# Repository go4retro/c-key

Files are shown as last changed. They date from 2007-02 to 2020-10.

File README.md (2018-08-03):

#Commodore PS/2 Keyboard Adapter

##License
Copyright (C) 2004 Jim Brain and RETRO Innovations

These files are free designs; you can redistribute them and/or modify
them under the terms of the GNU General Public License, version 2 as 
published by the Free Software Foundation.

These files are distributed in the hope that they will be useful,
but WITHOUT ANY WARRANTY; without even the implied warranty of
MERCHANTABILITY or FITNESS FOR A PARTICULAR PURPOSE.  See the
GNU General Public License for more details.

You should have received a copy of the GNU General Public License along
with these files; if not, write to the Free Software Foundation, Inc.,
51 Franklin Street, Fifth Floor, Boston, MA 02110-1301 USA.

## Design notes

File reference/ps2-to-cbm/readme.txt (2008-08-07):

Commodore to PS/2 keyboard & mouse adapter

0.0 Introduction

The Commodore to PS/2 keyboard & mouse adapter will let you use a regular PS/2 keyboard and PS/2 mouse on your Commodre 64 or VIC20. The keyboard is emulated using symbolic (not positional) mapping and the mouse emulates a 1531 mouse in proportional mode. 

0.1 Quick start guide

For those who don't like reading long documents, here is what you need:
- get all the parts listed in the "parts" section below
- assemble the circuit as per the schematic
- program the MCU
- connect C64, mouse, and keyboard

1.0 Parts

The following parts are required:

- Microcontroller PIC18F4520-I/P (40 pin DIP)
- Crosspoint switch MT8812AP1 (or MT8812AP)
- 10 MHz crystal
- 20-pin 0.100" header
- DE-9F connector 
- 6-pin min-DIN connector (qty 2)
- 220 ohm resistors (qty 15 or qty 2 8-way network)
- 180 ohm resistors (qty 16 or qty 2 8-way network)
- 150 ohm resistors (qty 3) (optional)
- 4.7 Kohm resistor (qty 4)
- 10 Kohm resistor
- LED (qty 3) (optional)
- 0.1 uF capacitor (qty 3)
- RCA connectors (qty 3) (optional)

2.0 Operation

2.1 Keyboard emulation
Almost all the PS/2 keys correspond to their C64 equivalents, so F1 is F1, CTRL is CTRL, etc.
The following five keys don't exist on the PS/2 keyboard so here are the substiutes:

C64 pound key      ==> PS/2 backslash  (\)
C64 left arrow key ==> PS/2 left quote (`)
C64 restore key	   ==> PS/2 pause/break
C64 run/stop key   ==> PS/2 esc
C64 commodore key  ==> PS/2 Windows key

Also, since three keys (@ ^ and +) require using the shift key, they themselves can't be combined with the shift key. This will only pose a problem if you're doing keyboard graphics (in which case a real C64 keyboard is probably more useful anyway since a PS/2 keyboard doesn't have the symbols on the front of the keys).

All the remaining keys on the PS/2 keyboard that don't map to a C64 equivalent will have no effect when pressed.

Caps Lock also has no effect since the typical function of a caps locks key is to only type uppercase letters, whereas the C64 "shift lock" key causes EVERY key to be shifted.

2.2 Mouse emulation

The mouse emulation simulates a 1531 mouse in proportional mode and is compatible with the 1531 driver for Geos. There is no emulation of a 1530 joystick-type mouse or of the 1531 in joystick mode.

2.3 Special functions

A few extra features are available:
If you have a Super Snapshot cartridge, connect the button to pin 2 of the CPU and pressing F12 will push the snapshot button.

If you have an A/B switch for your joystick, connect the control line to pin 23 of the CPU and pressing num lock will toggle between joystick 1 and joystick 2.

If you want to be able to reset your C64 from the keyboard, connect pin 24 of the CPU to the input of the 556 chip inside the C64 and pressing ctrl-alt-del will reset the C64.

3.0 Modifications

To compile the project, you will need the CCS compiler (www.ccsinfo.com) version 3.249. Version 4.xxx should work as well. From the "File" menu select "Open" and choose "main.c". Press F9 to compile.

Since the code only uses 22% of the ROM on the PIC18F4520, an equivalent CPU with less ROM can be used to save cost. 

To change the key mappings, edit TABLES.C and change the main translation table. Any PS/2 scancode can be mapped to any key, including the extra keys found on multimedia keyboards.

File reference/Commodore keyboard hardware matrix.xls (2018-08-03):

 | 13 br/wh | 19 red/wh | 18 or/wh | 17 yel/wh | 16 gr/wh | 15 bl/wh | 14 pur/wh | 20 gr/wh
12 brown | 1 | 3 | 5 | 7 | 9 | plus | brit# | inst/del
11 red | left arrow | W | R | Y | I | P | * | return
10 orange | ctrl | A | D | G | J | L | semicolon | rgh/lft
5 yellow | run stop | l-shift-lck | X | V | N | comma | slash | up/dwn
8 green | space | Z | C | B | M | period | r-shift | F1
7 blue | commodr | S | F | H | K | colon | equals | F3
6 purple | Q | E | T | U | O | at sign | up arrow | F5
9 gray | 2 | 4 | 6 | 8 | 0 | minus | clr/home | F7
4 5v
3 Restore | black/white
1 Ground

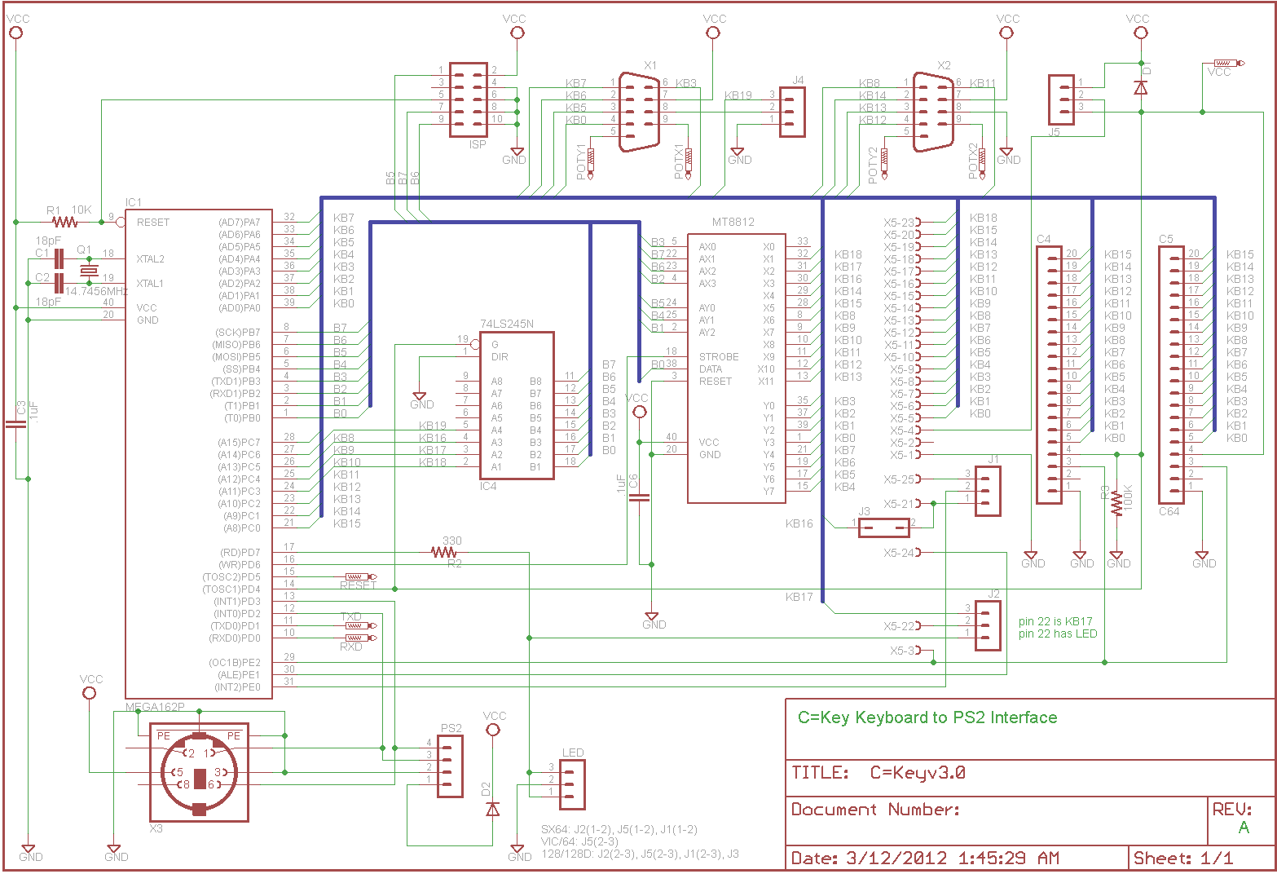
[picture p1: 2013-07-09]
pcb/C=Key 3.0a Schematic.png

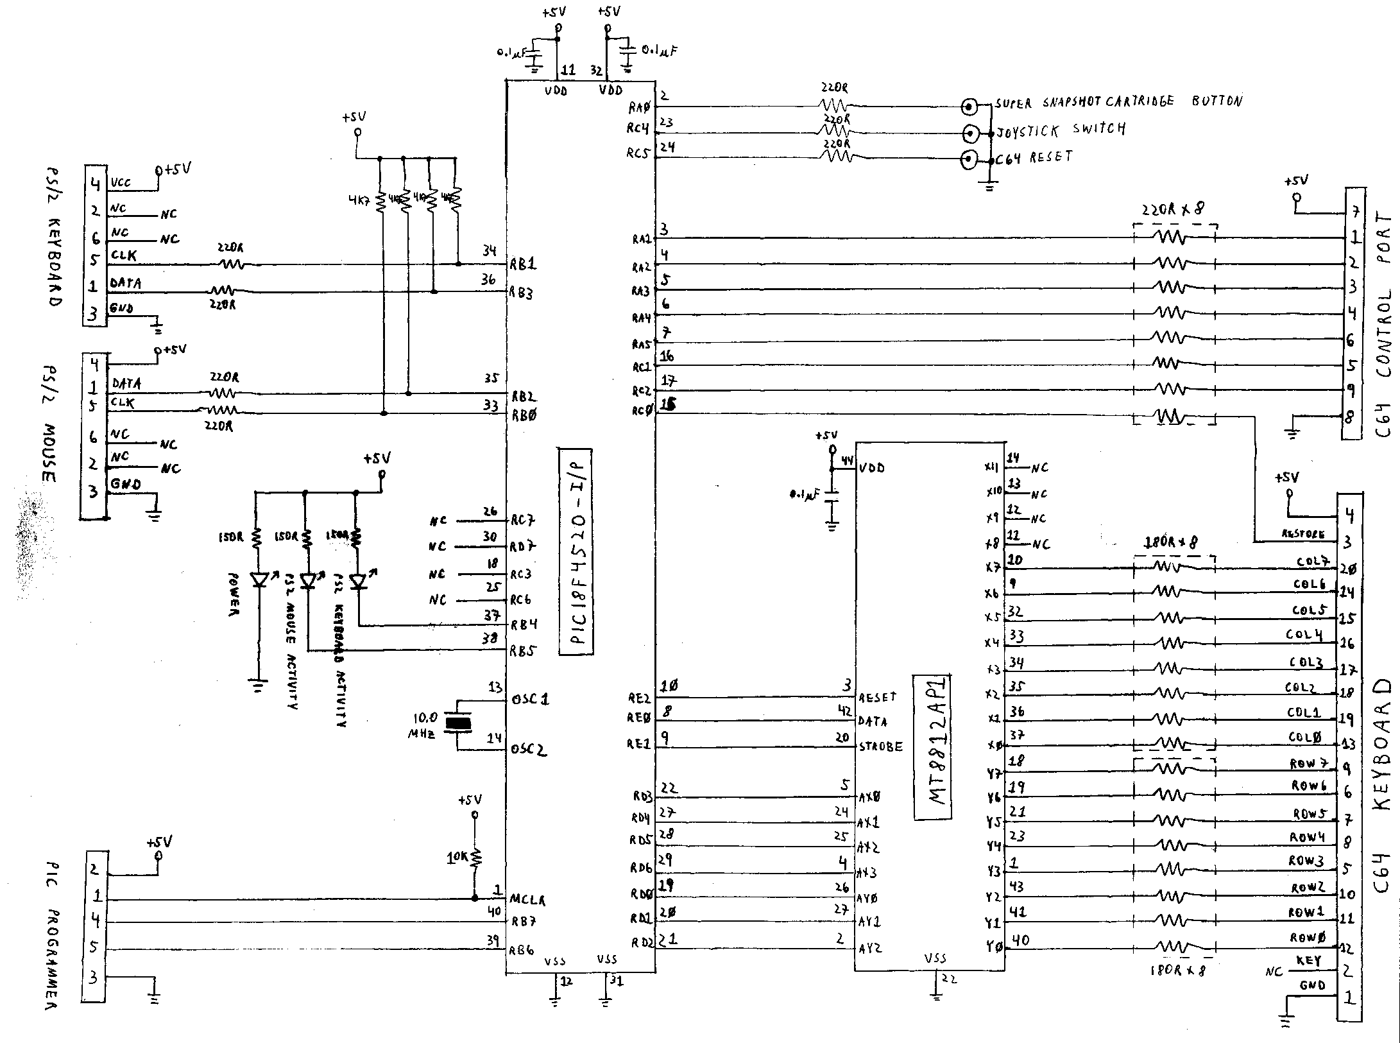
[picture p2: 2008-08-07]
reference/ps2-to-cbm/schematic.gif

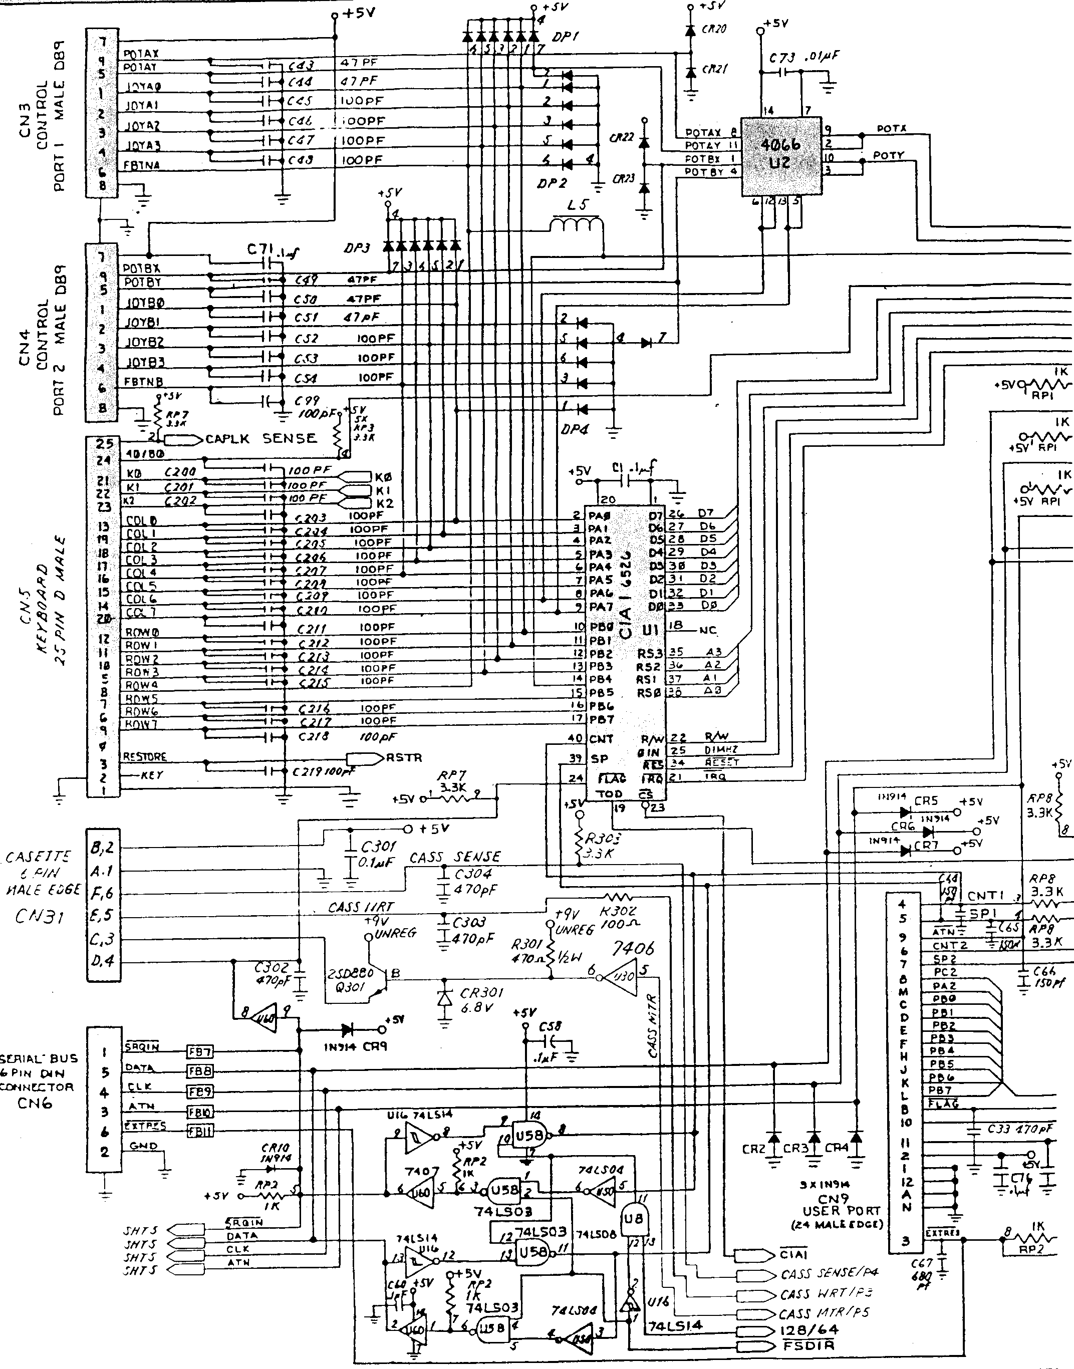
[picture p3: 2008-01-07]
reference/c128dcr-1-left.gif

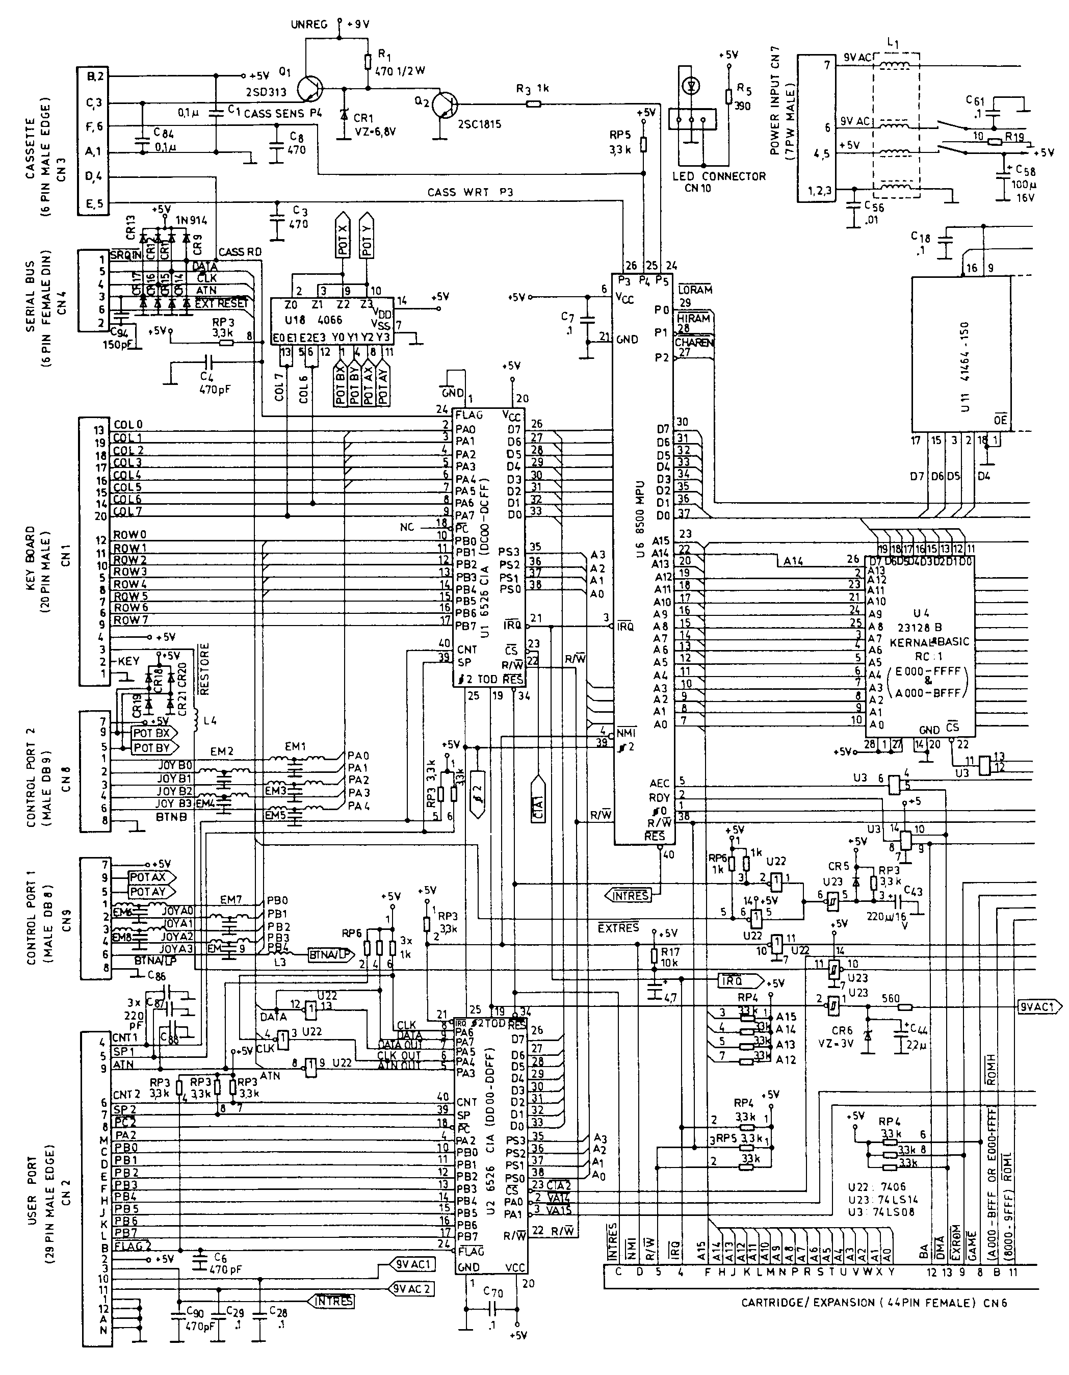
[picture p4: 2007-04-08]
reference/250469-rev.A-left.gif

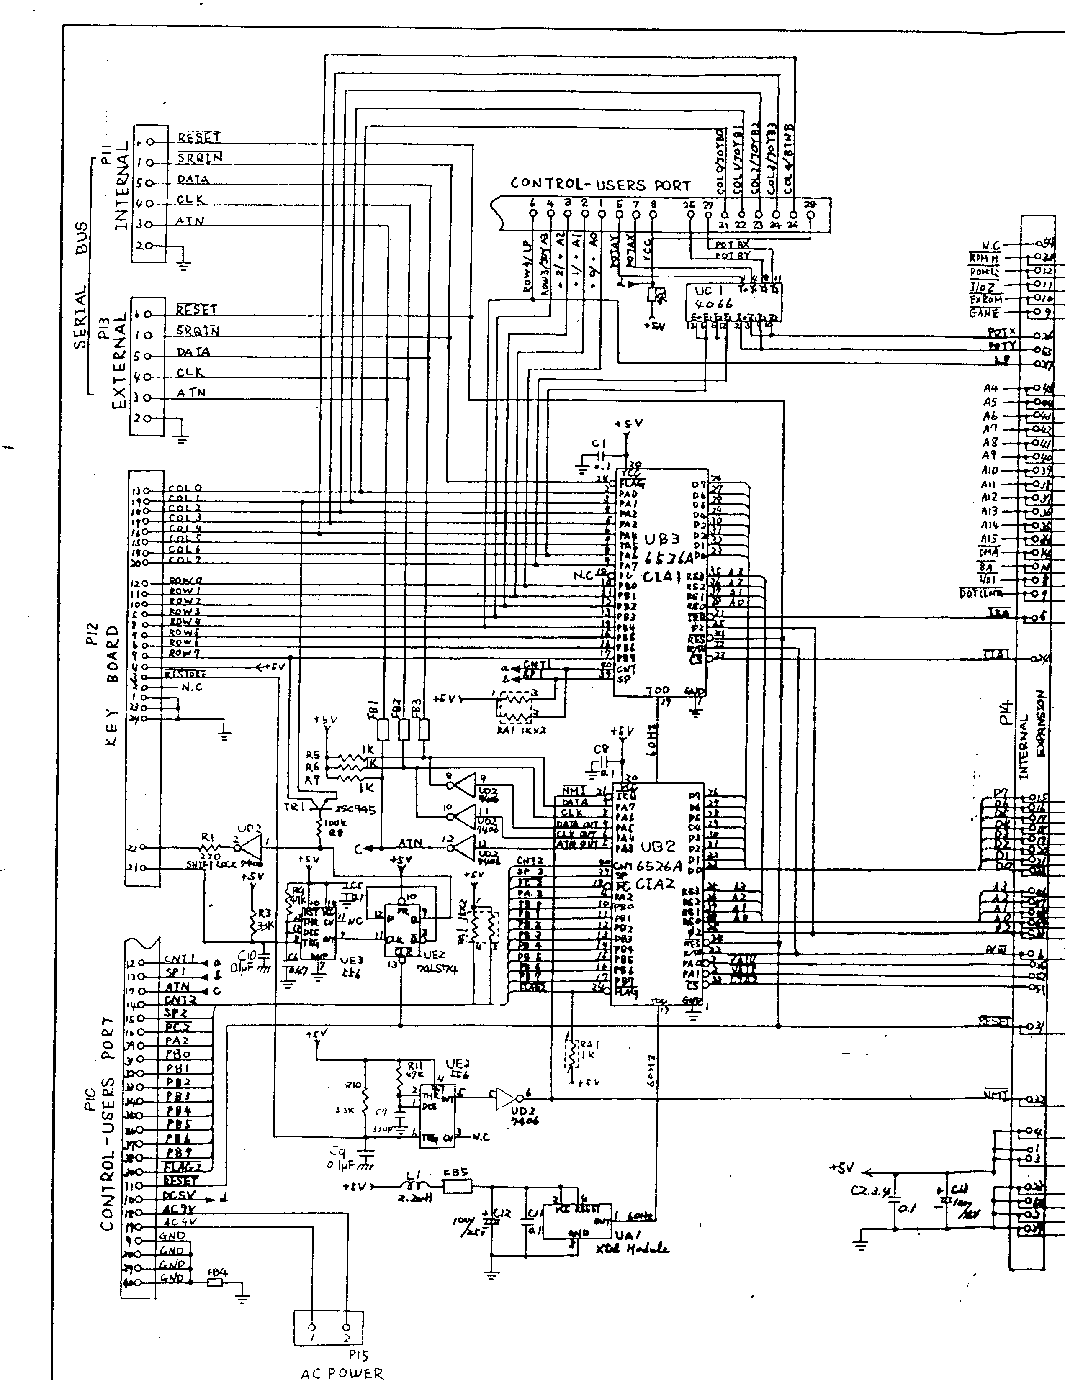
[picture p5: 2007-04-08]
reference/251107_l.gif

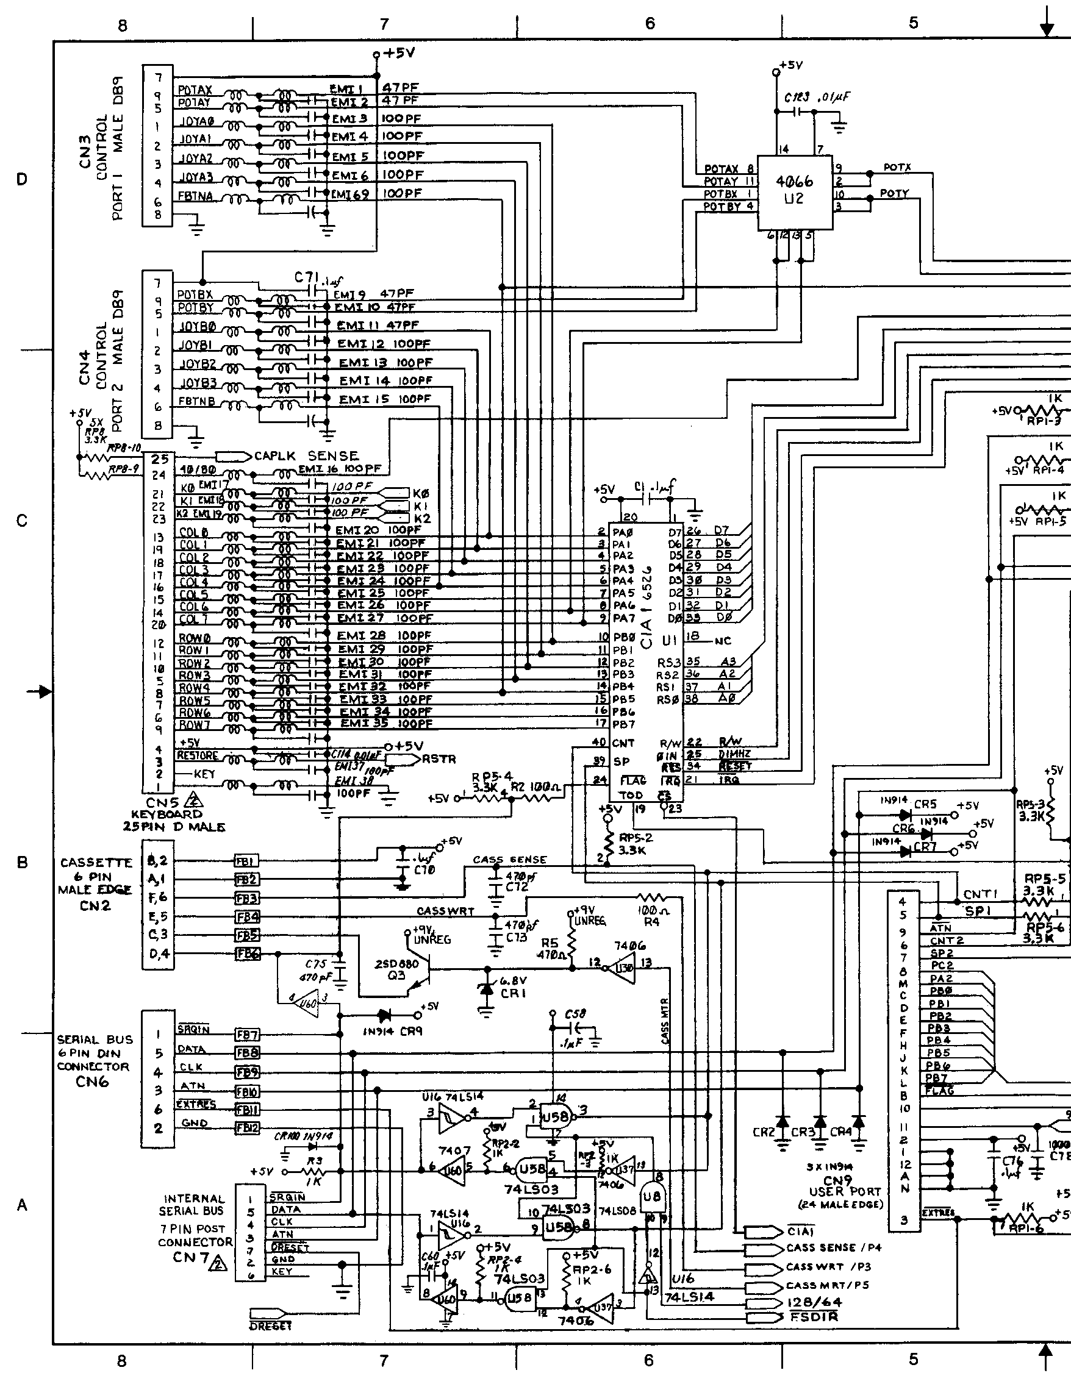
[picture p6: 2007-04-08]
reference/310378-3-left.gif

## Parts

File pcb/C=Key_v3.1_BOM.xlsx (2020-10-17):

Part | Value | Device | Quantity | Description | Source
C1,C2 | 18pF | C2.5/2 | 2 | CAPACITOR | https://www.digikey.com/en/products/detail/vishay-beyschlag-draloric-bc-components/K180J15C0GF5TL2/286458
C3,C6 | .1uF | C2.5/2 | 2 | CAPACITOR | https://www.digikey.com/en/products/detail/vishay-beyschlag-draloric-bc-components/K104K15X7RF5TL2/286538
C4 |  | MA20-1 | 1 | PIN HEADER | https://www.digikey.com/en/products/detail/sullins-connector-solutions/PPTC201LFBN-RC/810158
C5 | C64 | MA20-1 | 1 | PIN HEADER | https://www.digikey.com/en/products/detail/sullins-connector-solutions/PREC020SAAN-RC/2774834
D1,D2 |  | DIODE-DO41-10 | 2 | DIODE | https://www.digikey.com/en/products/detail/micro-commercial-co/1N4002-TP/773639
IC1 | MEGA162P | MEGA161P | 1 | MICROCONTROLLER | https://www.digikey.com/en/products/detail/microchip-technology/ATMEGA162-16PU/739761
IC2 | MT8812-P | MT8812-P | 1
IC4 | 74LS245N | 74LS245N | 1 | Octal BUS TRANSCEIVER, 3-state | https://www.digikey.com/en/products/detail/texas-instruments/SN74LS245N/277301
J1,J2,J5,LED |  | MA03-1 | 4 | PIN HEADER | https://www.digikey.com/en/products/detail/adam-tech/PH1-12-UA/9830395
J3 |  | JP1Q | 1 | JUMPER | https://www.digikey.com/en/products/detail/adam-tech/PH1-02-UA/9830266
PS2 |  | MA04-1 | 1 | PIN HEADER | https://www.digikey.com/en/products/detail/adam-tech/PH1-04-UA/9829296
Q1 | 14.7456MHz | CRYTALHC49U-V | 1 | CRYSTAL | https://www.digikey.com/en/products/detail/abracon-llc/ABL-14-7456MHZ-B2/675235
R1 | 10K | R-US_0204/5 | 1 | RESISTOR, American symbol | https://www.digikey.com/en/products/detail/stackpole-electronics-inc/CF18JT10K0/1741566
R2 | 330 | R-US_0204/5 | 1 | RESISTOR, American symbol | https://www.digikey.com/en/products/detail/stackpole-electronics-inc/CF18JT330R/1741683
R3 | 100K | R-US_0204/2V | 1 | RESISTOR, American symbol | https://www.digikey.com/en/products/detail/stackpole-electronics-inc/CF18JT100K/1741564
X1,X2 |  | M09HP | 2 | SUB-D | https://www.digikey.com/en/products/detail/assmann-wsw-components/A-DS-09-A-KG-T4S/1241806
X3 |  | MINI_DIN_6 | 1 | MINI_DIN_6 | https://www.digikey.com/en/products/detail/adam-tech/MDJ-006-FS/9832513
X5 |  | F25HPS | 1 | SUB-D | https://www.digikey.com/en/products/detail/amphenol-icc-fci/D25S33E4PA00LF/1538080

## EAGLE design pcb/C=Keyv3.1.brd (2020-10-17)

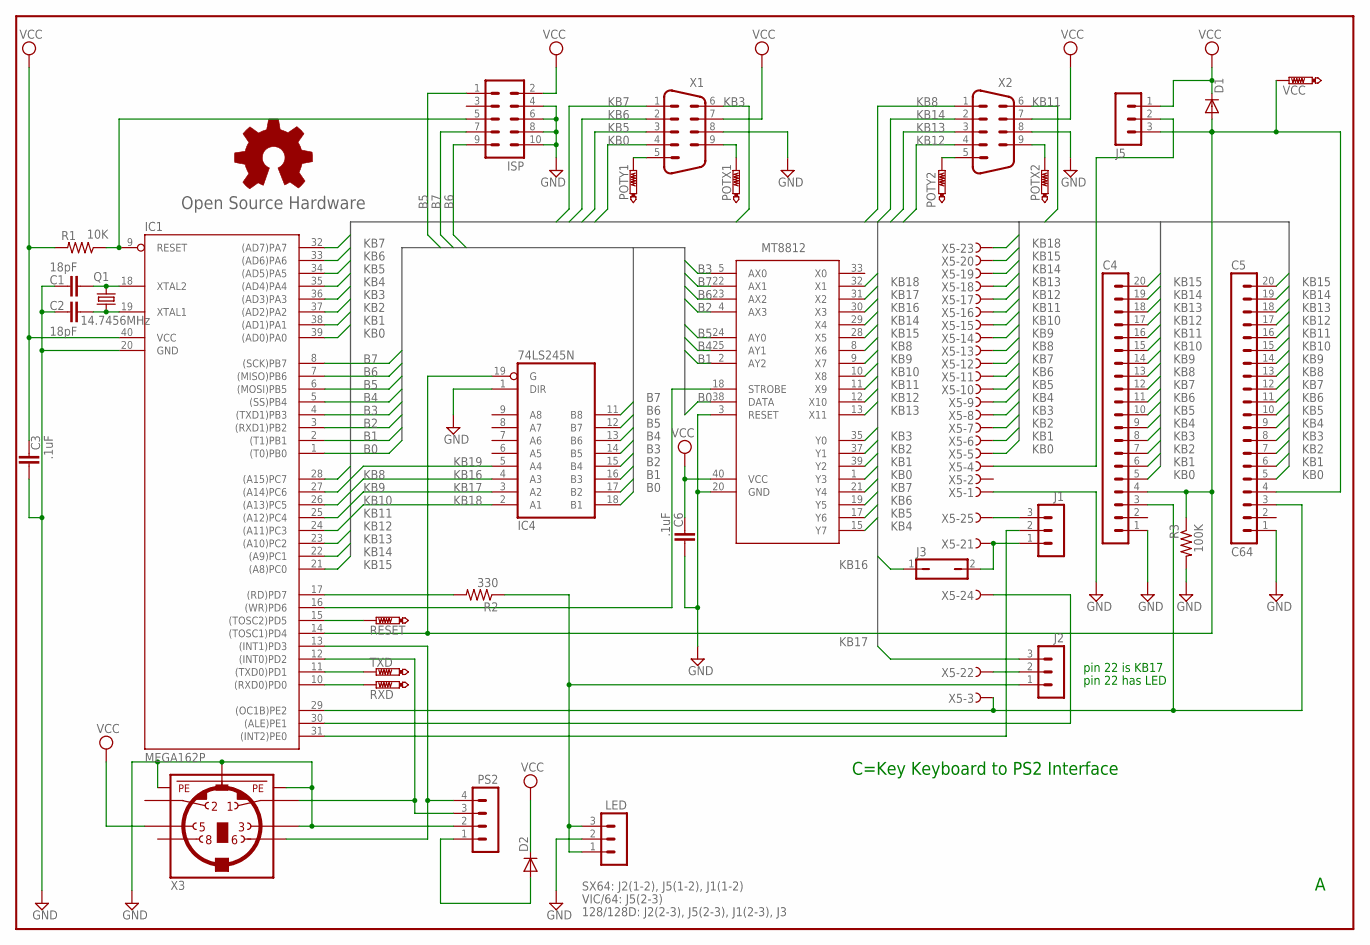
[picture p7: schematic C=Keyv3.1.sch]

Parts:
C1, C2: 18pF; C2.5-2
C3, C6: .1uF; C2.5-2
C4: MA20-1
C5: C64; MA20-1
D1, D2: DIODE-DO41-10; DO41-10
GOLD_ORB_SM1: Open Source Hardware; OSHW_5MM
IC1: MEGA162P; DIL40
IC2: MT8812-P; DIP40
IC4: 74LS245N; DIL20
ISP: MA05-2
J1, J2, J5: MA03-1
J3: JP1Q; JP1
LED: MA03-1
POTX1, POTX2: PTR1PAD1-13; P1-13
POTY1, POTY2: PTR1PAD1-13; P1-13
PS2: MA04-1
Q1: 14.7456MHz; HC49U-V
R1: 10K; 0204/5
R2: 330; 0204/5
R3: 100K; 0204V
RESET: PTR1PAD1-13; P1-13
RXD: PTR1PAD1-13; P1-13
TXD: PTR1PAD1-13; P1-13
VCC: PTR1PAD1-13; P1-13
X1, X2: M09HP
X3: MINI_DIN_6; M_DIN6
X5: F25HPS; F25HP

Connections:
B0: IC1.1 ((T0)PB0), IC2.38 (DATA), IC4.18 (B1)
B1: IC1.2 ((T1)PB1), IC2.2 (AY2), IC4.17 (B2)
B2: IC1.3 ((RXD1)PB2), IC2.4 (AX3), IC4.16 (B3)
B3: IC1.4 ((TXD1)PB3), IC2.5 (AX0), IC4.15 (B4)
B4: IC1.5 ((SS)PB4), IC2.25 (AY1), IC4.14 (B5)
B5: IC1.6 ((MOSI)PB5), IC2.24 (AY0), IC4.13 (B6), ISP.1
B6: IC1.7 ((MISO)PB6), IC2.23 (AX2), IC4.12 (B7), ISP.9
B7: IC1.8 ((SCK)PB7), IC2.22 (AX1), IC4.11 (B8), ISP.7
GND: C1.1, C2.1, C3.2, C4.1, C5.1, C6.2, IC1.20 (GND), IC2.3 (RESET), IC2.20 (GND), IC4.1 (DIR), IC4.10 (GND), ISP.4, ISP.6, ISP.8, ISP.10, LED.2, PS2.2, R3.2, X1.8, X2.8, X3.3, X3.SH1 (PE1), X3.SH2 (PE2), X3.SH3 (PE3), X5.1
KB0: C4.5, C5.5, IC1.39 ((AD0)PA0), IC2.1 (Y3), X1.4, X5.5
KB1: C4.6, C5.6, IC1.38 ((AD1)PA1), IC2.39 (Y2), X5.6
KB2: C4.7, C5.7, IC1.37 ((AD2)PA2), IC2.37 (Y1), X5.7
KB3: C4.8, C5.8, IC1.36 ((AD3)PA3), IC2.35 (Y0), X1.6, X5.8
KB4: C4.9, C5.9, IC1.35 ((AD4)PA4), IC2.15 (Y7), X5.9
KB5: C4.10, C5.10, IC1.34 ((AD5)PA5), IC2.17 (Y6), X1.3, X5.10
KB6: C4.11, C5.11, IC1.33 ((AD6)PA6), IC2.19 (Y5), X1.2, X5.11
KB7: C4.12, C5.12, IC1.32 ((AD7)PA7), IC2.21 (Y4), X1.1, X5.12
KB8: C4.13, C5.13, IC1.28 ((A15)PC7), IC2.8 (X6), X2.1, X5.13
KB9: C4.14, C5.14, IC1.27 ((A14)PC6), IC2.9 (X7), X5.14
KB10: C4.15, C5.15, IC1.26 ((A13)PC5), IC2.10 (X8), X5.15
KB11: C4.16, C5.16, IC1.25 ((A12)PC4), IC2.11 (X9), X2.6, X5.16
KB12: C4.17, C5.17, IC1.24 ((A11)PC3), IC2.12 (X10), X2.4, X5.17
KB13: C4.18, C5.18, IC1.23 ((A10)PC2), IC2.13 (X11), X2.3, X5.18
KB14: C4.19, C5.19, IC1.22 ((A9)PC1), IC2.29 (X4), X2.2, X5.19
KB15: C4.20, C5.20, IC1.21 ((A8)PC0), IC2.28 (X5), X5.20
KB16: IC2.30 (X3), IC4.4 (A3), J3.1
KB17: IC2.31 (X2), IC4.3 (A2), J2.3
KB18: IC2.32 (X1), IC4.2 (A1), X5.23
KB19: IC4.5 (A4)
unnamed: D2.A, PS2.1
unnamed: IC1.31 ((INT2)PE0), J1.2
unnamed: J1.3, X5.25
unnamed: J1.1, J3.2, X5.21
unnamed: J2.2, X5.22
unnamed: IC1.9 (RESET), ISP.5, R1.1
unnamed: IC1.15 ((TOSC2)PD5), RESET.1
unnamed: C4.4, C5.4, D1.A, IC1.14 ((TOSC1)PD4), IC4.19 (G), J5.3, R3.1, VCC.1
unnamed: J5.2, X5.4
unnamed: J2.1, LED.1, LED.3, R2.1
unnamed: POTX1.1, X1.9
unnamed: POTX2.1, X2.9
unnamed: POTY2.1, X2.5
unnamed: IC1.16 ((WR)PD6), IC2.18 (STROBE)
unnamed: IC1.10 ((RXD0)PD0), RXD.1
unnamed: IC1.11 ((TXD0)PD1), TXD.1
unnamed: IC1.12 ((INT0)PD2), PS2.3, X3.1
unnamed: IC1.13 ((INT1)PD3), PS2.4, X3.6
unnamed: C4.3, C5.3, IC1.29 ((OC1B)PE2), X5.3
unnamed: IC1.30 ((ALE)PE1), X5.24
unnamed: IC1.17 ((RD)PD7), R2.2
unnamed: C1.2, IC1.18 (XTAL2), Q1.2
unnamed: POTY1.1, X1.5
unnamed: C2.2, IC1.19 (XTAL1), Q1.1
VCC: C3.1, C6.1, D1.C, D2.C, IC1.40 (VCC), IC2.40 (VCC), IC4.20 (VCC), ISP.2, J5.1, R1.2, X1.7, X2.7, X3.5

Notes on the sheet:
C=Key Keyboard to PS2 Interface
pin 22 has LED
pin 22 is KB17
SX64: J2(1-2), J5(1-2), J1(1-2)
128/128D: J2(2-3), J5(2-3), J1(2-3), J3
VIC/64: J5(2-3)

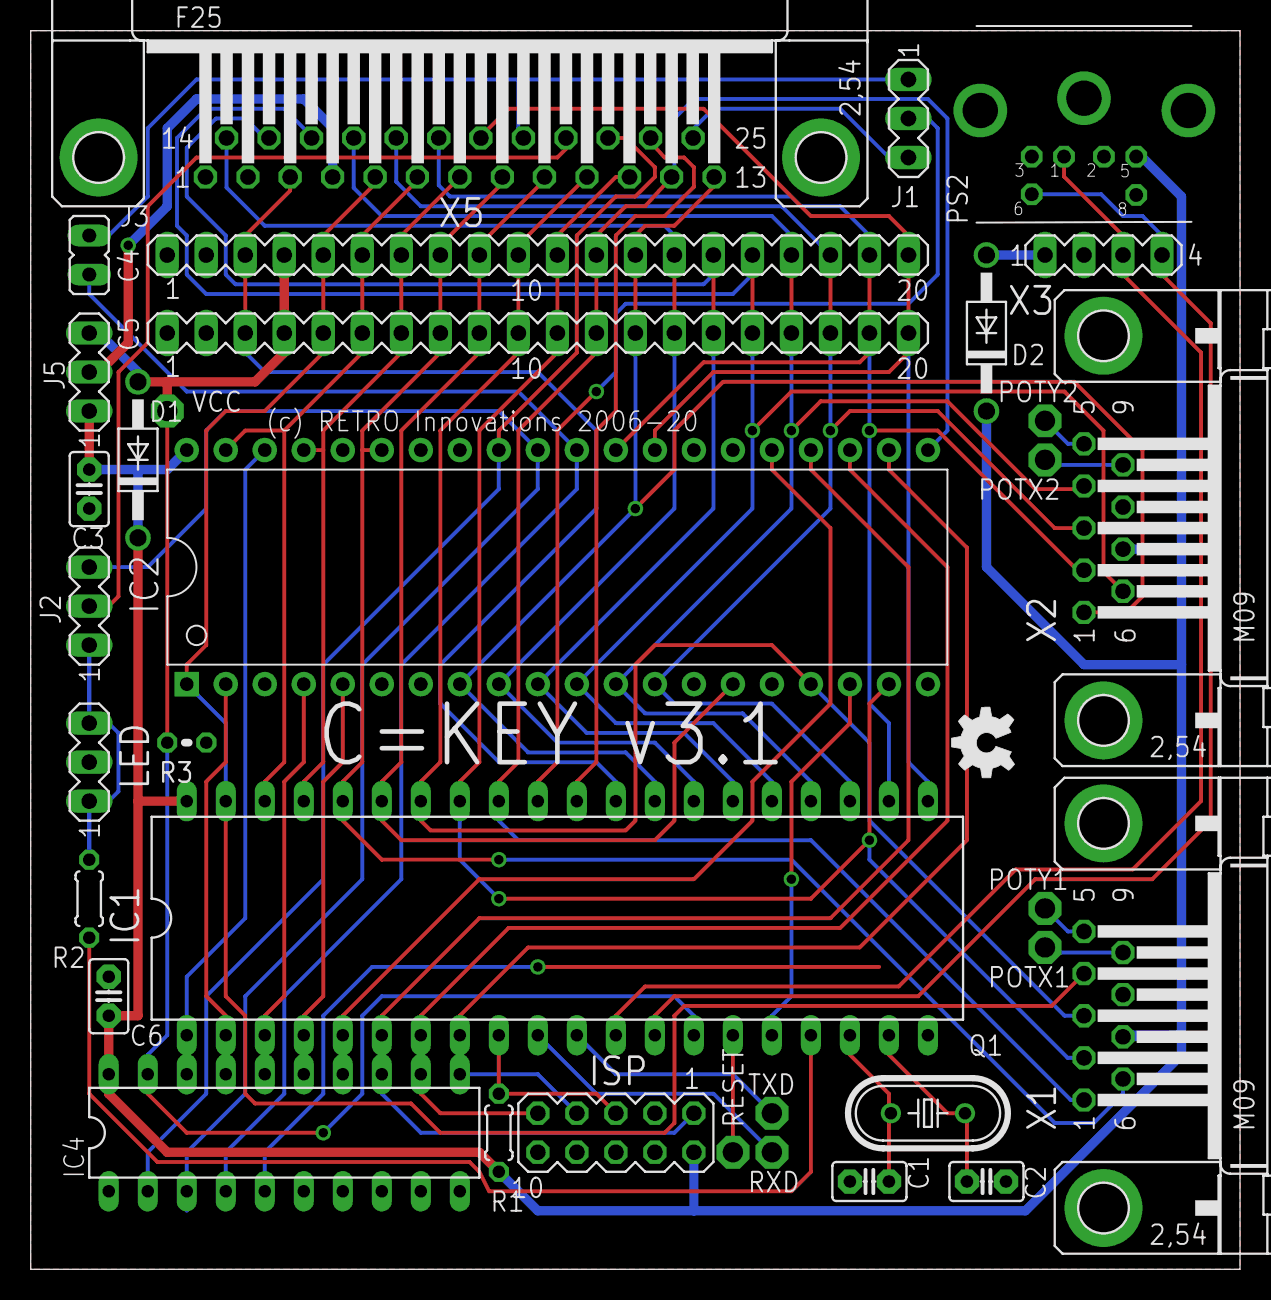
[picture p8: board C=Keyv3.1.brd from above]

Board: 2 copper layers, 78.7 x 80.6 mm, 35 parts (0 on the bottom side), 53 nets.

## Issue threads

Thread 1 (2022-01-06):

Keys get "stuck" sometimes

jakubpolomsky, 2022-01-06:
Hello,

I am not sure whether this is the right forum, but I think there might be an issue with the firmware. I am using the option PS/2 to C128D and everything worked first time, but I am experiencing a glitch. Every now and then a key gets "stuck" and repeats itself until I press it again. By every now and then I mean it happens approximately 1 time in 10 keypresses.

Thank you for the project in every case though! It is amazing!

go4retro, 2022-01-06:
Do you have another KB to try?  I wonder if the scanner is detecting a partially depressed key (sticky key)

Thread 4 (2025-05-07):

Switches don't work for PS/2 to C128D (solution provided)

tutigit, 2025-05-07:
I had a problem with the "40/80 DISPLAY" key. It toggles once and then doesn't go back.

Inserting a line to remove bit 7 in "sw_putc" seems to fix this.

before:

`void sw_putc( uint8_t sw) {
  // bit 7 indicates key up.
  uint8_t state=(sw & SW_UP);
  sw = _BV(sw); // turn into bit mask;
  if(sw & in_mask) {
    if(state) {
      // bring to input and set HI-Z
      PORT_SW_DDR &= (uint8_t)~sw;
      PORT_SW_OUT |= sw;
    } else {
      PORT_SW_DDR |= sw;
      PORT_SW_OUT &= (uint8_t)~sw;
    }
  }
}`

now:

`void sw_putc( uint8_t sw) {
  // bit 7 indicates key up.
  uint8_t state=(sw & SW_UP);
  **sw = sw & 0x7F; // tuti: cut of the state bit 7!**
  sw = _BV(sw); // turn into bit mask;
  if(sw & in_mask) {
    if(state) {
      // bring to input and set HI-Z
      PORT_SW_DDR &= (uint8_t)~sw;
      PORT_SW_OUT |= sw;
    } else {
      PORT_SW_DDR |= sw;
      PORT_SW_OUT &= (uint8_t)~sw;
    }
  }
}`

go4retro, 2025-06-07:
Thanks for the fix.  Updated and pushed.

Closed 2025-06-07.

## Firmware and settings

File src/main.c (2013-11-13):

/*
    C=Key - Commodore <-> PS/2 Interface
    Copyright Jim Brain and RETRO Innovations, 2004-2012

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
    main.c: Main application

*/
#include <inttypes.h>
#include <avr/interrupt.h>
#include "config.h"
#include "poll.h"
#include "ps2.h"
#include "scanner.h"
#include "uart.h"

ISR(TIMER2_COMP_vect) {
  if(MODE_DETECT) {
    poll_irq();
  } else {
    scan_irq();
  }
}

void main( void ) {
  uart_init();

  poll_init();  // do it here to reset cross-point switch everytime.
  if(MODE_DETECT) {
    ps2_init(PS2_MODE_HOST);
    uart_putc('H');
    //poll_init();  // do it above to reset cross-point switch everytime
    sei();
    poll();
  } else {
    ps2_init(PS2_MODE_DEVICE);
    uart_putc('D');
    scan_init();
    sei();
    scan();
  }
}

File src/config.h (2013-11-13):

/*
    C=Key - Commodore <-> PS/2 Interface
    Copyright Jim Brain and RETRO Innovations, 2004-2011

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
    config.h: User-configurable options to simplify hardware changes and/or
              reduce the code/ram requirements of the code.
*/

#ifndef CONFIG_H
#define CONFIG_H

#include "autoconf.h"

#define PS2_ENABLE_HOST
#define PS2_ENABLE_DEVICE
#define KB_SCAN_PORTS     // scan the KB ports for joystick activity

#ifndef TRUE
#define FALSE                 0
#define TRUE                  (!FALSE)
#endif

// log2 of the PS2 buffer size, i.e. 6 for 64, 7 for 128, 8 for 256 etc.
#define PS2_RX_BUFFER_SHIFT   3
#define PS2_TX_BUFFER_SHIFT   3

#define ENABLE_UART0
// log2 of the UART buffer size, i.e. 6 for 64, 7 for 128, 8 for 256 etc.
#define UART0_TX_BUFFER_SHIFT  3
//#define UART0_RX_BUFFER_SHIFT  3
#define UART0_BAUDRATE CONFIG_UART_BAUDRATE

#if CONFIG_HARDWARE_VARIANT == 1

#define MODE_DETECT       (PIND & (1 << PIN4))
#define RESET_INIT()      do {PORTD |= (1 << PIN5); } while(0)
#define RESET_ON()        do {DDRD |= (1 << PIN5); PORTD &= (uint8_t)~(1 << PIN5); } while(0)
#define RESET_OFF()       do {DDRD &= (uint8_t)~(1 << PIN5); PORTD |= ~(1 << PIN5); } while(0)

#define KB_ROW_HI_OUT     PORTB
#define KB_ROW_HI_IN      PINB
#define KB_ROW_HI_DDR     DDRB
#define KB_ROW_LO_OUT     PORTC
#define KB_ROW_LO_IN      PINC
#define KB_ROW_LO_DDR     DDRC
#define KB_COL_OUT        PORTA
#define KB_COL_IN         PINA
#define KB_COL_DDR        DDRA

#define PS2_CLK_DDR       DDRD
#define PS2_CLK_OUT       PORTD
#define PS2_CLK_IN        PIND
#define PS2_CLK_PIN       _BV(PD3)
#define PS2_DATA_DDR      DDRD
#define PS2_DATA_OUT      PORTD
#define PS2_DATA_IN       PIND
#define PS2_DATA_PIN      _BV(PD2)

#define PORT_SW_OUT       PORTE
#define PORT_SW_IN        PINE
#define PORT_SW_DDR       DDRE

#define XPT_PORT_DATA_OUT   PORTB
#define XPT_DDR_DATA        DDRB
#define XPT_PORT_STROBE_OUT PORTD
#define XPT_DDR_STROBE      DDRD

#define XPT_PIN_STROBE (1<<PIN6)

#define SW_4080         PIN1
#define SW_CAPSENSE     PIN0
#define SW_RESTORE      PIN2

#endif

#ifdef CONFIG_DEBUG_DATA
#define debug(x)          uart_putc(x)
#else
#define debug(x)          do {} while(0)
#endif

#endif /*CONFIG_H*/

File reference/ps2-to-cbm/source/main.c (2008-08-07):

// This project is compiled with the PCWH compiler v3.249 from CCS. 


#include "config.h"
#include "defs.h"
#include "pinouts.h"
#include "reg-18f4520.h"

// Since CCS 3.249 doesn't have a linker, all source files have to be #INCLUDED in the main source file
#include "ps2.c"
#include "paddles.c"
#include "pulse-io.c"
#include "crosspoint.c"
#include "tables.c"
#include "translation.c"
#include "keyboard.c"
#include "mouse.c"


void main() {
	setup_adc_ports(NO_ANALOGS|VSS_VDD);
	setup_adc(ADC_OFF|ADC_TAD_MUL_0);
	setup_psp(PSP_DISABLED);
	setup_spi(FALSE);
	setup_wdt(WDT_OFF);
	setup_timer_0(RTCC_INTERNAL|RTCC_DIV_256);	// 0.1 us X 256 = 25.6 us per tick X 65536 = 1677.721 ms per period
	setup_timer_1(T1_INTERNAL|T1_DIV_BY_1);
	setup_timer_2(T2_DISABLED,0,1);
	setup_timer_3(T3_DISABLED|T3_DIV_BY_1);
	setup_comparator(NC_NC_NC_NC);
	setup_vref(FALSE);
	setup_low_volt_detect(FALSE);
	setup_oscillator(FALSE);

	output_a  (INITIAL_PORTA_VALUE);
	output_b  (INITIAL_PORTB_VALUE);
	output_c  (INITIAL_PORTC_VALUE);
	output_d  (INITIAL_PORTD_VALUE);
	output_e  (INITIAL_PORTE_VALUE);
	set_tris_a(INITIAL_TRISA_VALUE);
	set_tris_b(INITIAL_TRISB_VALUE);
	set_tris_c(INITIAL_TRISC_VALUE);
	set_tris_d(INITIAL_TRISD_VALUE);
	set_tris_e(INITIAL_TRISE_VALUE);

	printf("Startup\n\r");
	crosspoint_init();
	paddle_init();
	ps2_init();
	enable_interrupts(GLOBAL);
	keyboard_init();
	mouse_init();

	while(1) {
		keyboard_handler();
		mouse_handler();
		pulse_handler();
	}
	sleep();
}

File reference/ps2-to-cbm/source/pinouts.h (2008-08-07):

#define SNAPSHOT_BTN		PIN_A0
#define JOYSTICK0			PIN_A1
#define JOYSTICK1			PIN_A2
#define JOYSTICK2			PIN_A3
#define JOYSTICK3			PIN_A4
#define JOYSTICK4			PIN_A5
#define NC_A6				PIN_A6
#define NC_A7				PIN_A7

#define	INITIAL_PORTA_VALUE	0b00000000
#define	INITIAL_TRISA_VALUE	0b11111111

#define PS2_CLK0			PIN_B0
#define PS2_CLK1			PIN_B1
#define PS2_DATA0			PIN_B2
#define PS2_DATA1			PIN_B3
#define KEYBOARD_LED		PIN_B4
#define MOUSE_LED			PIN_B5
#define ICD_PGC				PIN_B6
#define ICD_PGD				PIN_B7

#define	INITIAL_PORTB_VALUE	0b00110000
#define	INITIAL_TRISB_VALUE	0b11001111

#define RESTORE				PIN_C0
#define PADDLE1				PIN_C1
#define PADDLE2				PIN_C2
#define JOYSWITCH_INHIBIT	PIN_C3
#define JOYSWITCH_SELECT	PIN_C4
#define CBM_RESET_LINE		PIN_C5
#define SER_TX				PIN_C6
#define SER_RX				PIN_C7

#define	INITIAL_PORTC_VALUE	0b00000000
#define	INITIAL_TRISC_VALUE	0b11100111

#define CROSSPOINT_AY0		PIN_D0
#define CROSSPOINT_AY1		PIN_D1
#define CROSSPOINT_AY2		PIN_D2
#define CROSSPOINT_AX0		PIN_D3
#define CROSSPOINT_AX1		PIN_D4
#define CROSSPOINT_AX2		PIN_D5
#define CROSSPOINT_AX3		PIN_D6
#define NC_D7				PIN_D7

#define	INITIAL_PORTD_VALUE	0b10000000
#define	INITIAL_TRISD_VALUE	0b10000000

#define CROSSPOINT_DATA		PIN_E0
#define CROSSPOINT_STROBE	PIN_E1
#define CROSSPOINT_RESET	PIN_E2

#define	INITIAL_PORTE_VALUE	0b00000000
#define	INITIAL_TRISE_VALUE	0b00000000

#use fast_io (A)
#use fast_io (B)
#use fast_io (C)
#use fast_io (D)
#use fast_io (E)


#define PS2_DATA_PORT		B
#define PS2_CLK_PORT		B
#define JOYSTICK_IO_PORT	A

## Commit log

2007-02-05 Initial code for PC -> 64 direction
    [C=Key.brd, C=Key.sch, C=Keyv1.1.brd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]
2007-02-05 Switch to MEGA162 and merge directions
2007-04-08 In order to more closely approximate the joystick electrical connection on the 64/128, changed the code to support reading the joysticks on the actual KB row and col pins. As a result, had to redo th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
    Also, changed some includes to fix case issues.
    [C=Keyv2.0.brd, C=Keyv2.0.sch, C=Keyv3.0.brd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]
2007-04-13 Created new PCB using correct C128/128 kb connector, and will be easier to place in 64/128 units. As well, laid out joysticks to coincide with placement on real 64/128
    [C=Keyv3.0.brd, C=Keyv3.0.sch]
2007-05-15 o Modified code to work with v3 board o Fixed init code in switch.c (setting DDR and then reading too fast caused false readings) o Fixed issue in PS2 GET DEVICE ID command handling o Set LEDs to HI/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
    [C=Keyv3.0.brd, C=Keyv3.0.sch, Commodore keyboard hardware matrix.xls]
2007-12-17 Added code to generalize the MODE pin for v2 and v3 designs.
2007-12-17 Fixed mnemonic on FLAG
    [poll64.h]
2007-12-17 Minor LED init fix
2007-12-18 Fixed prototype for SW_send
2007-12-18 Added jumper for SX64 KB operation and fixed diode drill sizes
    [C=Keyv3.0.brd, C=Keyv3.0.sch]
2007-12-19 Added configuration code to Host mode, added EEPROM saving, and rewrote LED routines
2007-12-25 More code cleanup, and more to do.
    [C=Keyv2.0.brd, C=Keyv3.0.sch]
2008-01-07 CBM KB -> PS2 bugfixes and code cleanup.
    [C=Keyv3.0.brd, C=Keyv3.0.sch, Mappings.xls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]
2008-08-07 Save reference materials
2008-08-07 Added doc directory
    [Mappings.xls]
2008-08-07 Small tweaks for production board layout
    [C=Keyv3.0.brd, C=Keyv3.0.sch]
2008-08-07 Switch to better CPU define in source files
2008-08-07 Migrated to better uart code
    [Mappings.xls, pricelist.xls]
2008-08-08 Final tweaks to kb driver
2008-08-08 Cleanup of uart driver
2012-03-12 Fixed PS/2 routines to PS/2 KB LED commands work Merged in uart code from PS2Encoder and fixed some compilation options.
    Jim
    [C=Keyv3.0.sch]
2012-03-12 Fixed PS/2 routines to PS/2 KB LED commands work Merged in uart code from C=Key and fixed some compilation options.
    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
    [uart.c]
2014-03-16 Missed an old M16 target item
    [poll64.h]
2018-08-03 General cleanup for git
    [C=Keyv1.0.brd, C=Keyv1.0.sch, Commodore keyboard hardware matrix.xls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]
2018-10-21 Fix case statement warning about implicit fallthrough.
2020-10-17 A few minor changes
    * Removed useless joystick ground strap on pcb
    * Don't turn on 40/80 by default
    * Add in BOM
    [C=Key_v3.1_BOM.xlsx, C=Keyv3.1.brd, C=Keyv3.1.sch]
2021-03-06 Use full swing crystal setting in fuses

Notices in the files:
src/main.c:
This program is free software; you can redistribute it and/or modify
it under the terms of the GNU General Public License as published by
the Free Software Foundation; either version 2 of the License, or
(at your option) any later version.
